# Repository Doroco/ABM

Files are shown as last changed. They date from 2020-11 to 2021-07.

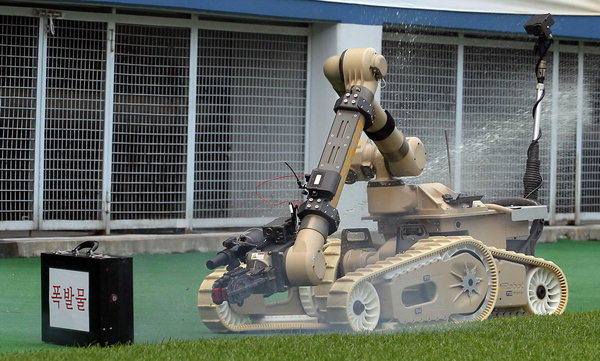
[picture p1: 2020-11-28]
설계파일/final_only/image/부엉이/L20140818.22019191557i1.jpg

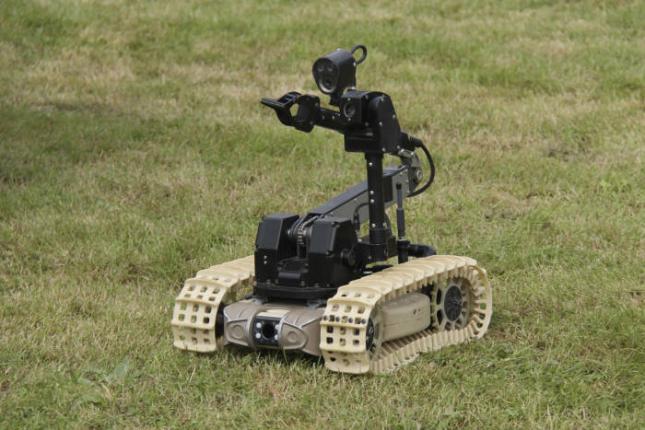
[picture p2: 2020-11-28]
설계파일/final_only/image/부엉이/799672_20160509152558_325_0002.jpg

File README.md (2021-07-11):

# Autonomous driving DDMR agent  

로봇팔이 부착된 Mobile robot이 다양한 Task를 수행합니다.

- 프로젝트 5분 소개영상
https://youtu.be/9r_tR3T8_8s

## 목차

- System Architecture
- Hardware Architecture
- 구현내용
- Project Secenarios
- Reference

### System Architecture
시스템아키텍쳐

### Hardware Architecture
하드웨어 아키텍쳐

### 구현내용

- 모터제어

Global_PathPlanning

- DWA(Dynamic Window Approach)

DWA_SIM

- 실제 주행

ezgif com-gif-maker (2)

- 3-DOF Inverse Kinematics

ezgif com-gif-maker (2)

- Ros와 MCU간의 Serial 통신

### Project Scenarios

- 세부기술 정리(준비중): https://doroco.github.io/ 

### reference
- [1]Fox, D., Burgard, W., & Thrun, S. (1997). The dynamic window approach to collision avoidance. IEEE Robotics & Automation Magazine, 4(1), 23–33. 
- [2]강형석, 「제어기 설계를 위한 DC 모터의 모델 파라미터 측정 및 실험적 보정」, 『한국정밀공학회지』, 제 31권 12호, 한국정밀공학회, pp1147-1154.
김상훈 저,⒊『(DC,AC,BLDC)모터제어』, 서울 : 복두출판사, 2010,pp54-115.
https://pinkwink.kr/732
- [3]Rached Dhaouadi, Dynamic Modelling of Differential-Drive Mobile Robots using Lagrange and Newton-Euler Methodologies: A Unified Framework,Adv Robot Autom,2013,pp3-6.
- [4]Modern Robotics, Kevin M.Lynch, Frank C.Park
.

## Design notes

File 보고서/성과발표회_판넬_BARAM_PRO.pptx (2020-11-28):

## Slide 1

2020학년도 2학기 참빛설계학기(학생주도형) 성과발표회

BARAM_PRO

안전사고감지 및 스마트 초동조치 시스템

창의융합형

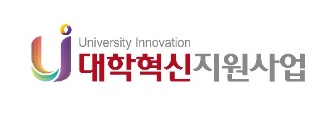
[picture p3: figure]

지도교수 / 최익
(로봇학부)

[개발 배경]

다양한 재난 대응 로봇이 개발되고 있지만, 여러가지 한계점을 보이고 있다.
그 중 재난 초기에 투입 불가능한 문제점을 보완하고자 한다.

[기존 재난 대응 로봇]

재난 발생 초기에는 대피 인원, 구조 요원 등 다양한 동적 물체가 존재
기존 로봇은 물체를 회피하는 것이 불가능 하여 주로 후속조치를 위해 투입

팀원 / 함병일, 최승완
이동규, 이호석 (로봇학부)

[초기 재난 대응 로봇 필요성]

재난 초기에 로봇을 투입하여 초기에 사고를 진압할 수 있도록 한다.

[로봇에 필요한 기술]

Sensing을 통해 사고위치와 자신의 위치, 주변의 환경을 파악한다.
물체 회피를 알고리즘을 통해 충돌로 인한 2차 피해를 방지하며 이동한다.
로봇과 user간의 Data 주고 받기 위한 통신 환경 구축

[System Architecture]

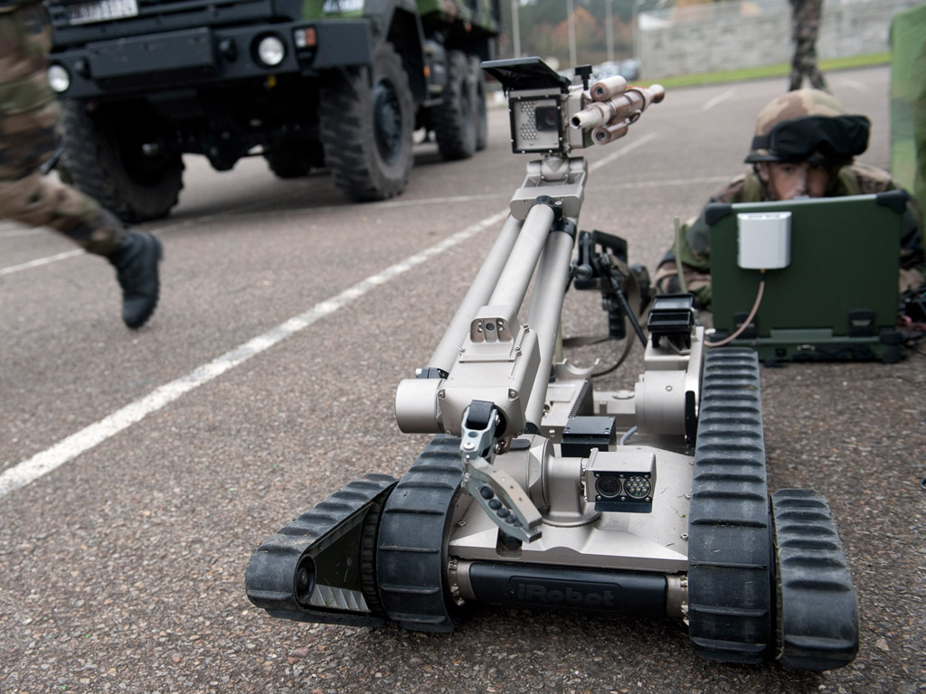
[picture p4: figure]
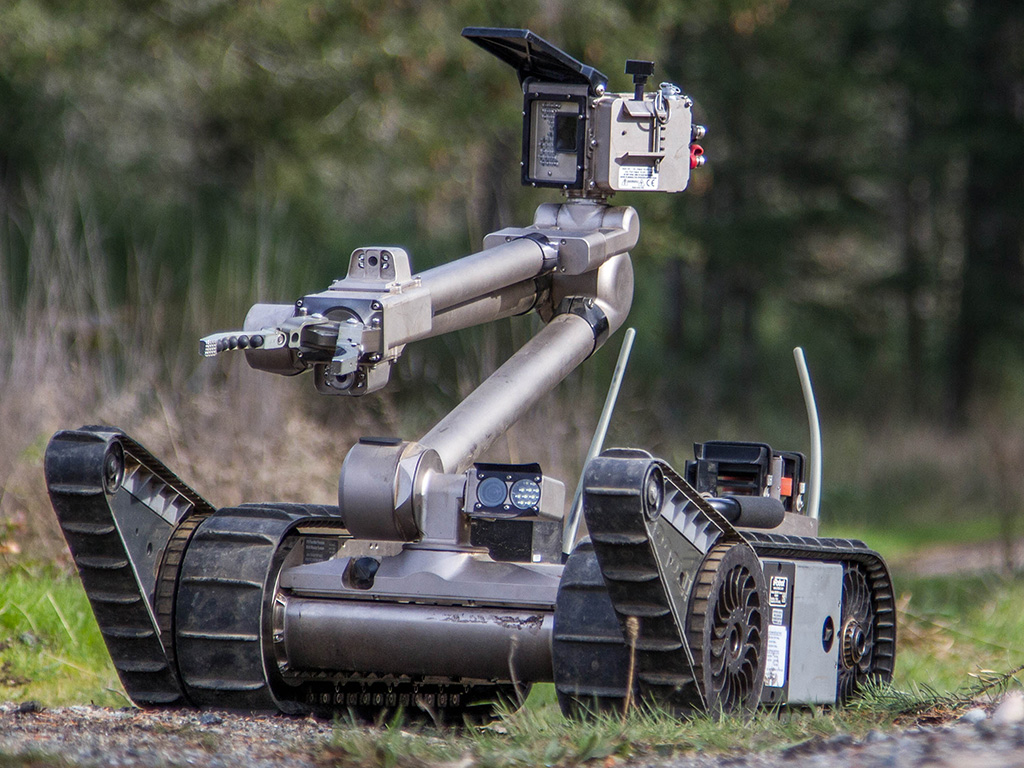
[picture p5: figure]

목표지점 도달 시 초동조치를 위한
로봇 팔 구동

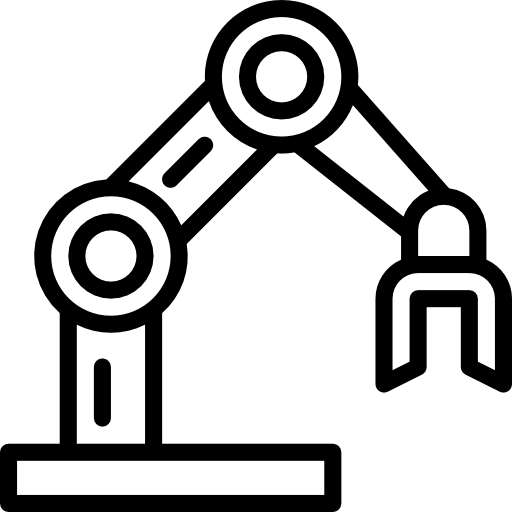
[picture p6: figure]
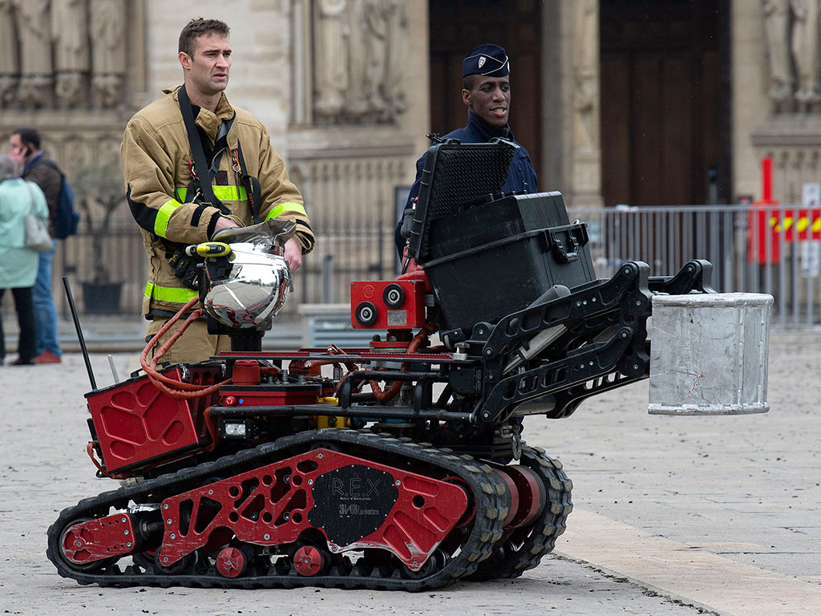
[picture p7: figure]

네비게이션& 회피
LiDAR

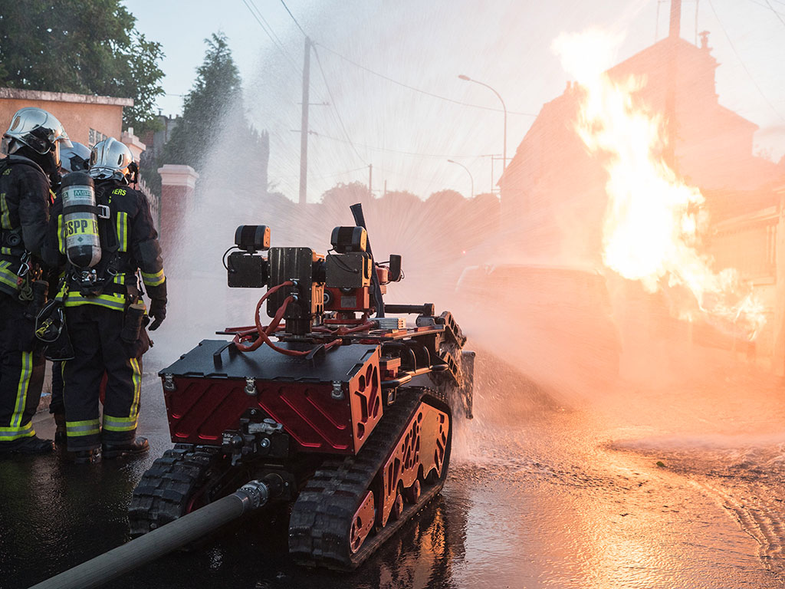
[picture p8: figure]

[개발 목표]

동적 물체를 피하며 최단경로로
목표지점 도달

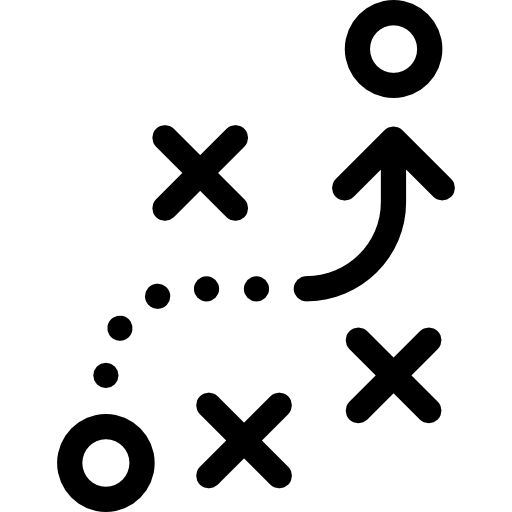
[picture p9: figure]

[하드웨어 구성]

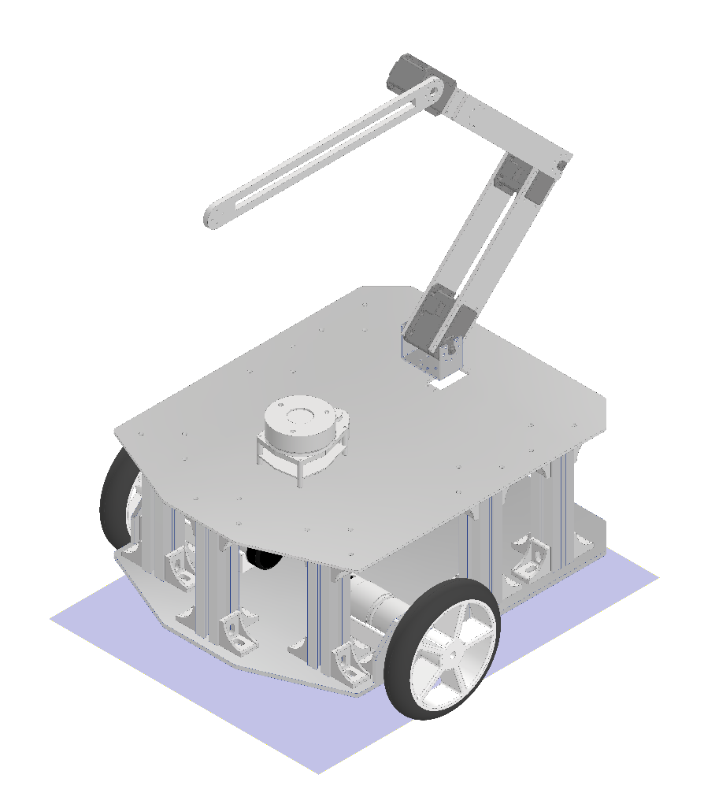
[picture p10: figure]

초동조치
로봇 팔

모바일 로봇

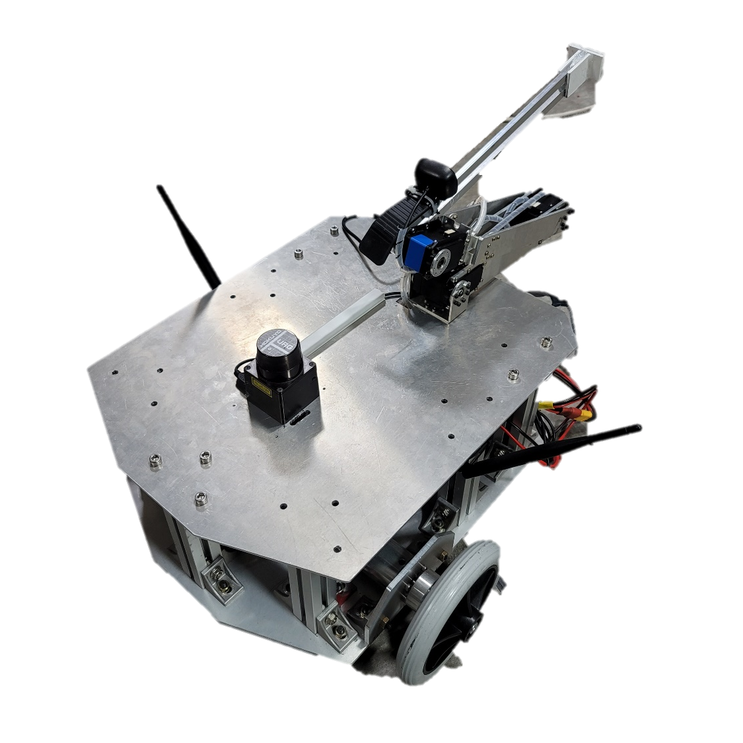
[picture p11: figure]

DDMR

Motor

Encoder

Encoder

Motordriver
(LMD18200)

Motordriver
(LMD18200)

Hardware
DDMR & Manipulator

Current
sensor

Current
sensor

uart

MCU
(STM32F401RE)

Odometry

Robot Pose EKF

v, ω target

Software
Slam & Motion planing

Gmapping

localization

mapping

map image

원격으로 사고 현장 확인
관리자의 판단에 따른 능동적인 조작 기능

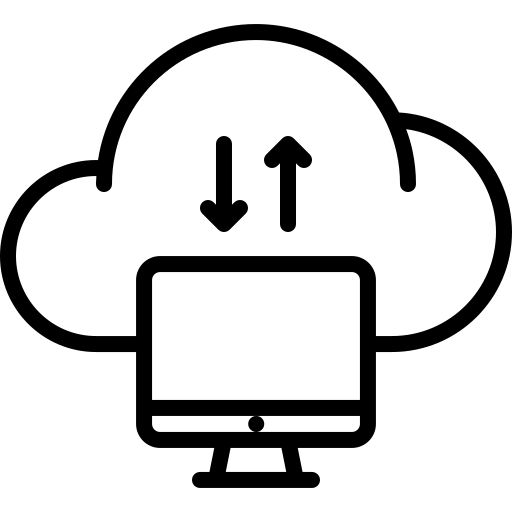
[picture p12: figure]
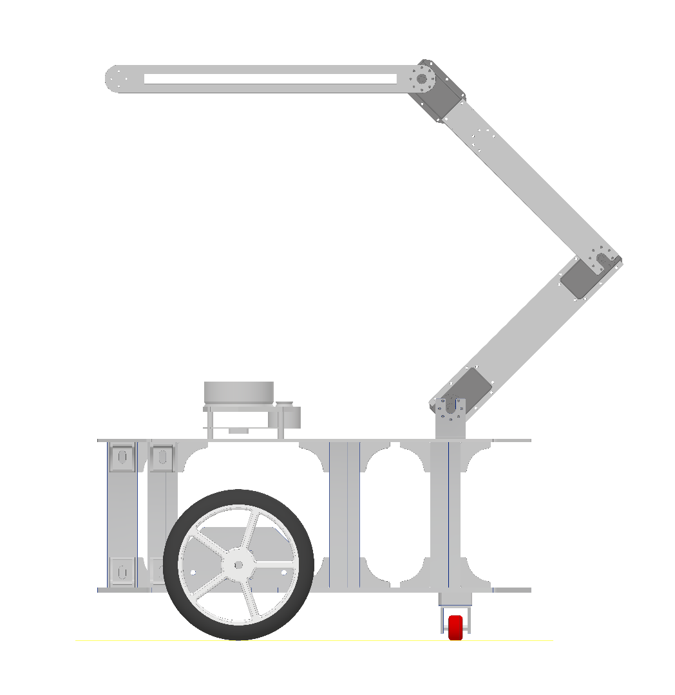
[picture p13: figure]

Manipulator

EX-106

Motor

EX-106

Controller

LiDAR

Camera

scan data

OpenCV

Manipulator state

Navigation

Global Path Planning

waypoint

local Path Planning

object
position

State check

Robot Pose

[구현 시나리오 1]

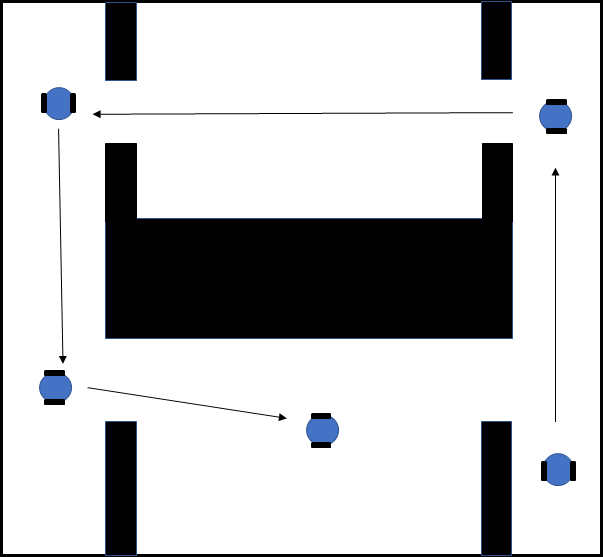
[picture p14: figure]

로봇이 장애물을 피해 자유롭게 움직이며 주변 환경 정보를 저장

[구현 시나리오 2]

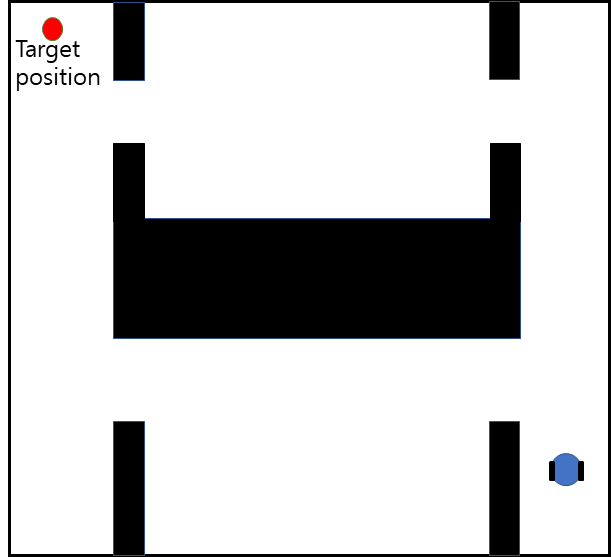
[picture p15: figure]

로봇은 초기위치에서 출발하여, 최단 경로로 목적지에 도착

[구현 시나리오 3]

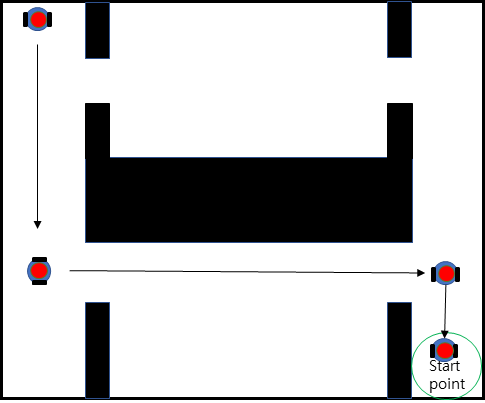
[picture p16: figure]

목적지에서 임무 수행 후 새롭게 정해진 목적지로 이동

EX-106

RS485

HSV

Labeling

Motion planning

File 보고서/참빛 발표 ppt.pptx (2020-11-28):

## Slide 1

안전사고 감지 및 스마트 초동조치 시스템

BARAM_PRO
School of Robotics
지도교수 : 최익
팀원 : 함병일, 최승완, 이동규, 이호석

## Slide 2

Project Introduction

Motive for Selection

1. 다양한 재난 대응 로봇이 연구 개발되고 있지만, 여러가지 한계점을 보이고 있다.
2. 그 중 재난 초기에 투입 불가능한 문제점을 보완하고자 한다.

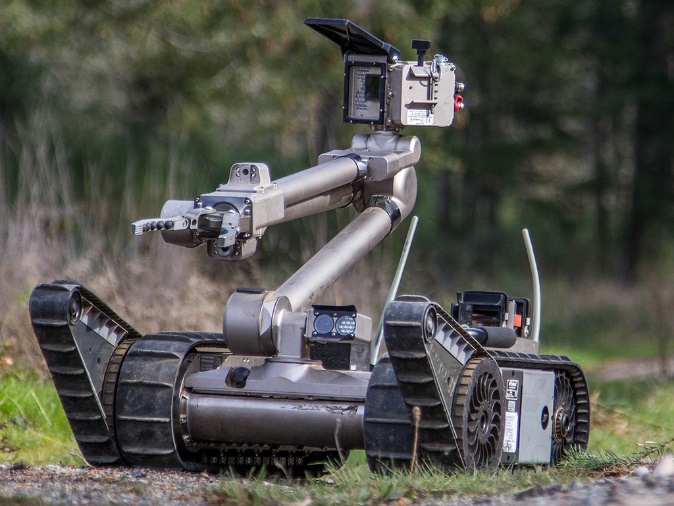
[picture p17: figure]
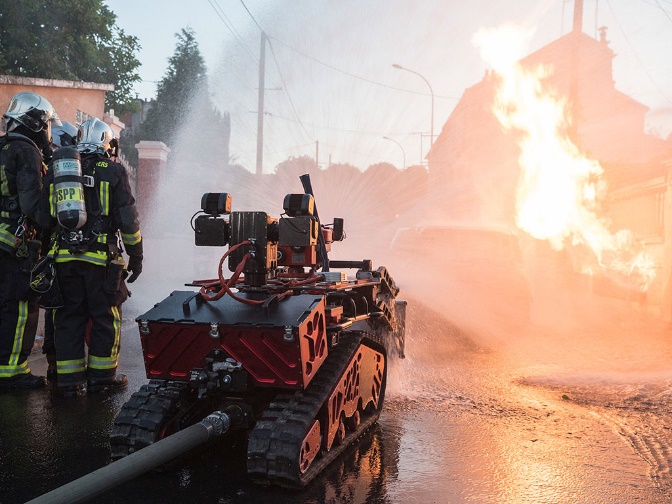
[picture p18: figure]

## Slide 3

Project Introduction

Development Goals

1. 동적 물체를 회피하여 최단 경로로 목표 지점 도달
2. 초동조치를 위한 Manipulator 구동
3. 원격으로 사고 현장 확인
4. 관리자의 판단에 따른 능동적인 조작 기능

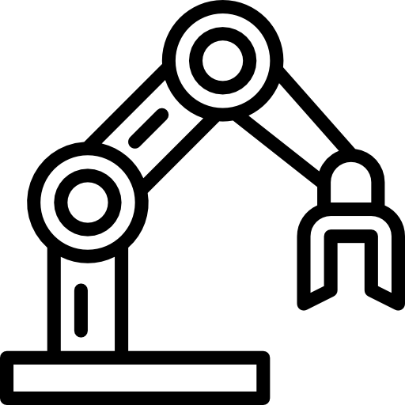
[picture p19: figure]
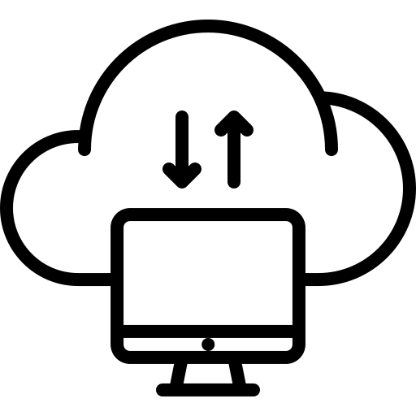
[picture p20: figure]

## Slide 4

Project Contents

Hardware Architecture

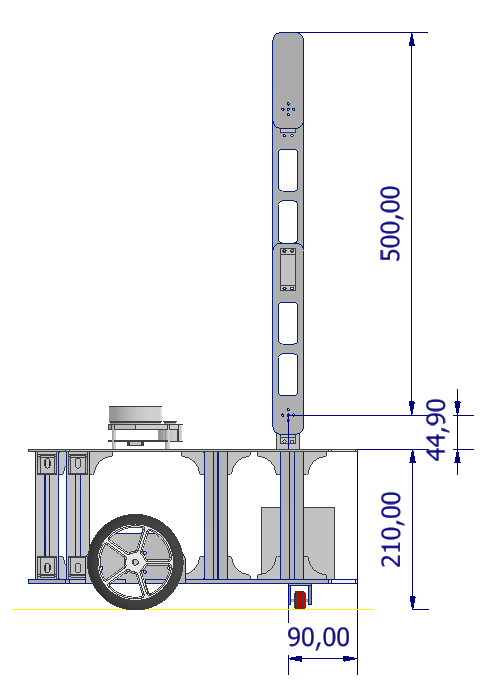
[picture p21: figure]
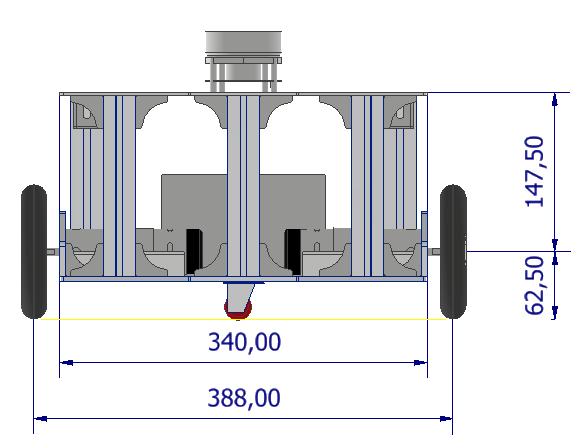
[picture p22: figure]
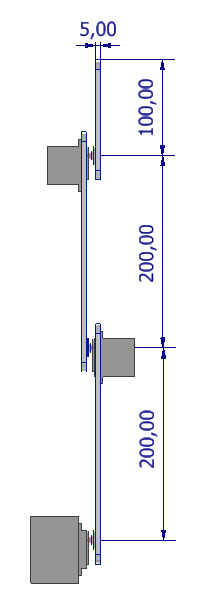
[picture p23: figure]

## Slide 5

Project Contents

System Architecture

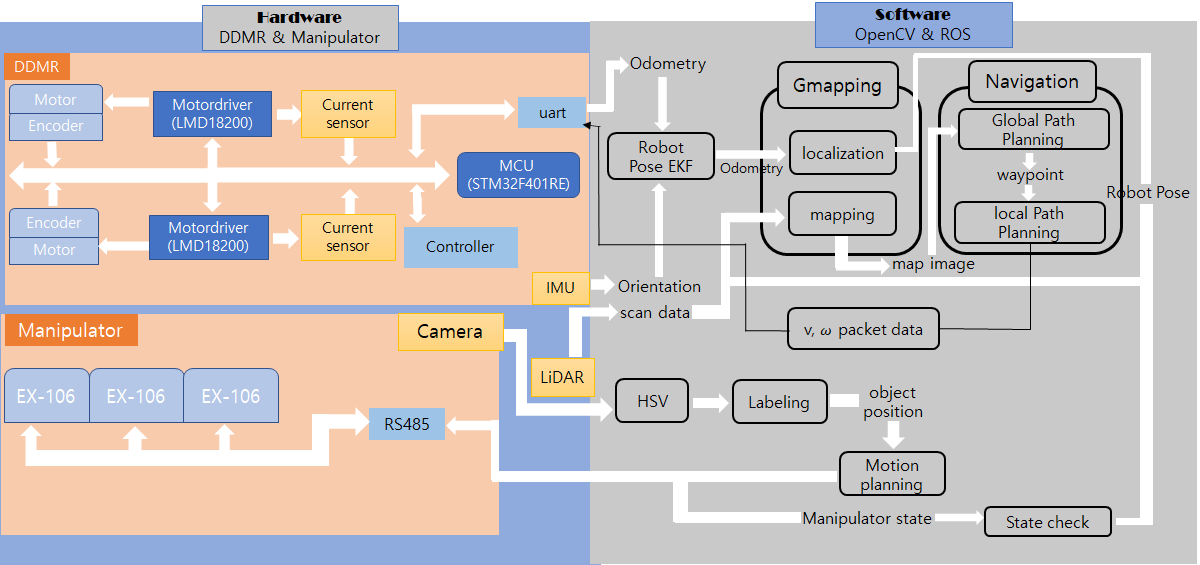
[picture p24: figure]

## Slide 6

Project Contents

Dynamic Window Approach

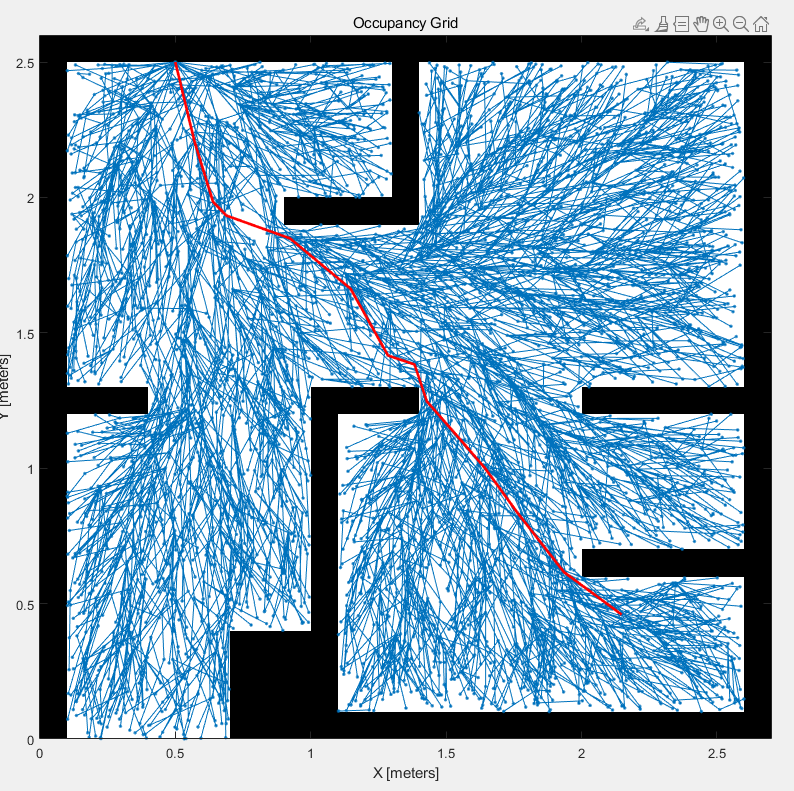
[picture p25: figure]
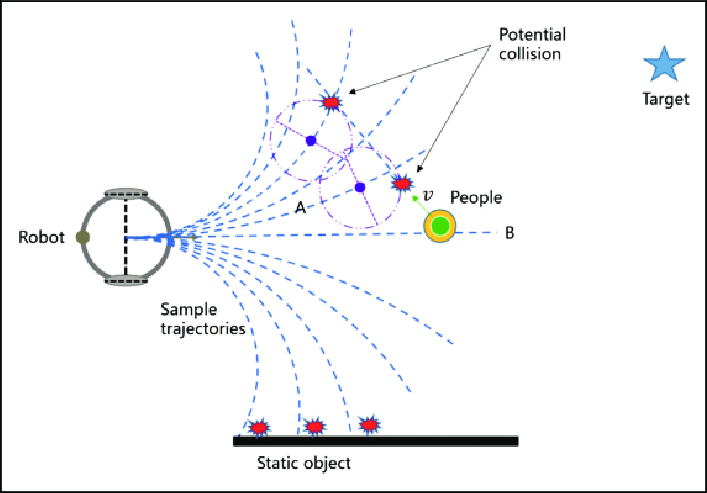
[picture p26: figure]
Illustration of the improved DWA method. DWA: dynamic window approach.

cost(v,ω)=α∙heading(v,ω)+β∙dist(v,ω)+γ∙vel(v,ω)

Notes: 출처:https://www.researchgate.net/figure/Illustration-of-the-improved-DWA-method-DWA-dynamic-window-approach_fig10_317584521
출처:Hugo Berti, A. Sappa, O. AgamennoniPublished 2008EngineeringLatin American Applied Research

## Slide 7

Project Contents

Motor Control


Brushed DC Motor Control System Block Diagram

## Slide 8

Project Contents

Motor Control


Current Control


Position Control

Speed Control

Dynamics

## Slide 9

Project Contents

Manipulator

A planar 3-DOF robot manipulator for simulation. All the links have the... | Download Scientific Diagram

Screw Axes

Newton Raphson Method

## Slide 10

Project Contents

Project Scenarios


로봇이 장애물을 피해 자유롭게 움직이며 주변 환경 정보를 저장


로봇은 초기위치에서 출발하여, 최단 경로로 목적지에 도착

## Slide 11

Project Contents

Project Scenarios


목적지에서 임무 수행 후 새롭게 정해진 목적지 또는 출발지점으로 이동

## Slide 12

Thank You
For Your Attention

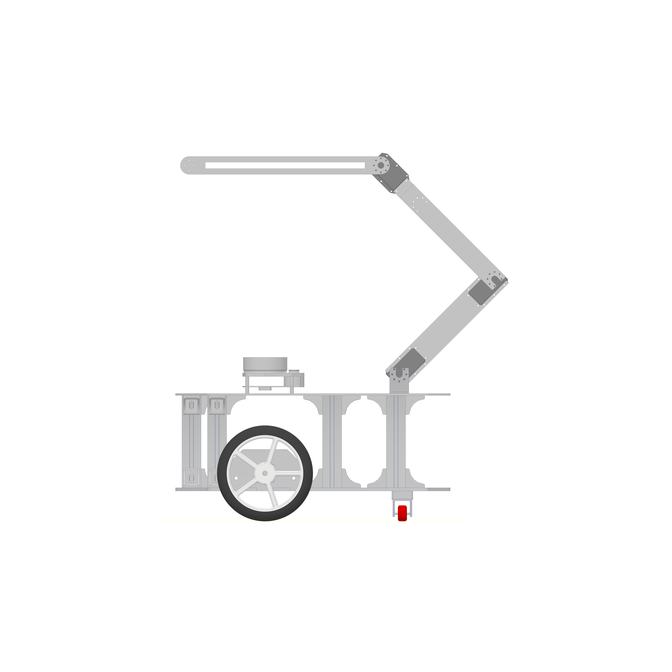
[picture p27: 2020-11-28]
설계파일/final_only/image/부엉이/final_side.tiff

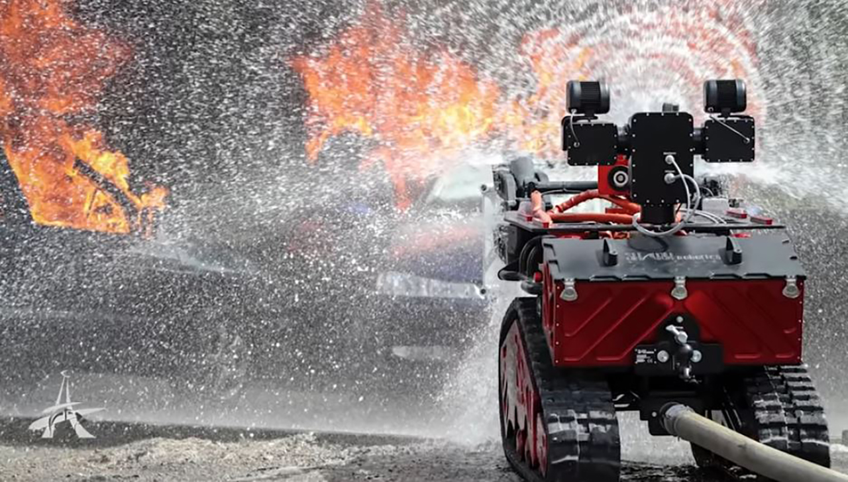
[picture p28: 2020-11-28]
설계파일/final_only/image/부엉이/201904181640067609_img_00.jpg

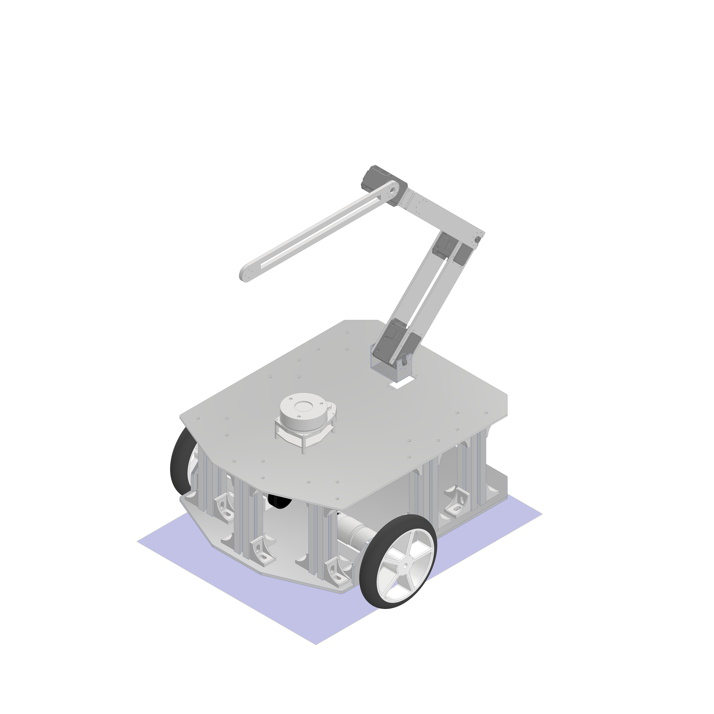
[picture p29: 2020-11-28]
설계파일/final_only/image/부엉이/final.tiff

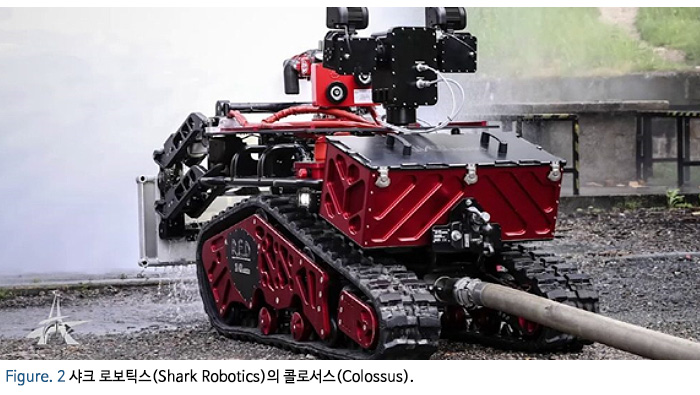
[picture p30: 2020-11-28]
설계파일/final_only/image/부엉이/20200918_pjy_03.jpg

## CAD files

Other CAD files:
설계파일/final_only/145pi_wheel/145pi_tire.iam
설계파일/final_only/145pi_wheel/OldVersions/145pi_tire.0006.iam
설계파일/final_only/145pi_wheel/OldVersions/tire.0007.ipt
설계파일/final_only/145pi_wheel/OldVersions/wheel.0002.ipt
설계파일/final_only/145pi_wheel/tire.ipt
설계파일/final_only/145pi_wheel/wheel.ipt
설계파일/final_only/LIDAR/OldVersions/RPLIDAR_A1.0005.iam
설계파일/final_only/LIDAR/OldVersions/base.0001.ipt
설계파일/final_only/LIDAR/OldVersions/base.0002.ipt
설계파일/final_only/LIDAR/OldVersions/sensor.0001.ipt
설계파일/final_only/LIDAR/RPLIDAR_A1.iam
설계파일/final_only/LIDAR/base.ipt
설계파일/final_only/LIDAR/sensor.ipt
설계파일/final_only/LIDAR/wheel.ipt
설계파일/final_only/bottom.ipt
설계파일/final_only/braket2.ipt
설계파일/final_only/castor/OldVersions/castor_1inch.0010.iam
설계파일/final_only/castor/OldVersions/castor_link.0002.ipt
설계파일/final_only/castor/OldVersions/castor_link2.0005.ipt
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

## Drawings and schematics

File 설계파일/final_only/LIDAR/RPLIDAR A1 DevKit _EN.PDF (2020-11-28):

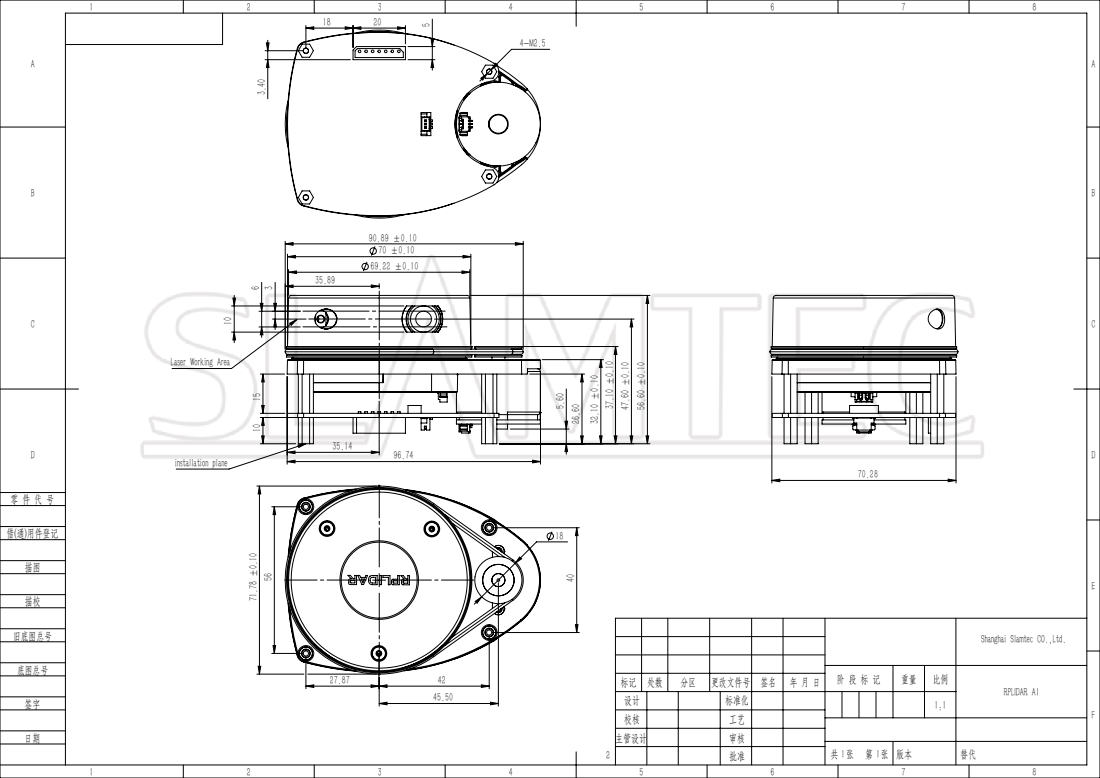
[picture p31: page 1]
installation plane

Laser Working Area

Shanghai Slamtec CO.,Ltd.

阶 段 标 记 | 重量 | 比例 | RPLIDAR A1

标记 | 处数 | 分区 | 更改文件号 | 签名 | 年 月 日
设计 | | | 标准化 | | | | | 1:1
校核 | | | 工艺
主管设计 | | | 审核

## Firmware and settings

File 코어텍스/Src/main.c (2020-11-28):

/**
  ******************************************************************************
  * @file           : main.c
  * @brief          : Main program body
  ******************************************************************************
  ** This notice applies to any and all portions of this file
  * that are not between comment pairs USER CODE BEGIN and
  * USER CODE END. Other portions of this file, whether 
  * inserted by the user or by software development tools
  * are owned by their respective copyright owners.
  *
  * COPYRIGHT(c) 2020 STMicroelectronics
  *
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
  ******************************************************************************
  */
/* Includes ------------------------------------------------------------------*/
#include "main.h"
#include "stm32f4xx_hal.h"

/* USER CODE BEGIN Includes */
#include "string.h"
#include "math.h"

/* USER CODE END Includes */

ADC_HandleTypeDef hadc1;
DMA_HandleTypeDef hdma_adc1;

TIM_HandleTypeDef htim2;
TIM_HandleTypeDef htim3;
TIM_HandleTypeDef htim4;

UART_HandleTypeDef huart6;
DMA_HandleTypeDef hdma_usart6_rx;

/* USER CODE BEGIN PV */
#define dt 0.0002
#define dt2 0.0001
#define dt10 0.02
#define pi 3.141592653589793
#define ppr 3724
#define RX_BUFFER_SIZE 18
#define TX_BUFFER_SIZE 12
#define R 0.075
#define L 0.2125
#define get_dma_data_length() huart6.hdmarx->Instance->NDTR
#define get_dma_total_size() huart6.RxXferSize
//#define tau 0.00048

volatile int32_t encoder_cnt_R = 0;
volatile int32_t encoder_cnt_L = 0;
volatile int32_t encoder_cnt_pre_R = 0;
volatile int32_t encoder_cnt_pre_L = 0;

volatile int16_t cnt_R = 0;
volatile int16_t cnt_L = 0;

volatile double angular_velocity_R = 0;
volatile double angular_velocity_L = 0;
volatile double angular_velocity_pre_R = 0;
volatile double angular_velocity_pre_L = 0;
volatile double theta_R = 0;
volatile double theta_L = 0;
volatile double delta_s = 0;
volatile double delta_theta = 0;

//volatile int g_cnt = 0;

volatile uint16_t Motor_CCR_R = 0;
volatile uint16_t Motor_CCR_L = 0;
volatile uint16_t timer = 0;
volatile uint16_t ctimer = 0;
volatile uint16_t ptimer = 0;
volatile uint16_t ktimer = 0;


volatile double rep_r = 0;
volatile double rep_l = 0;
volatile double rep_pre_r = 0;
volatile double rep_pre_l = 0;
volatile double Kps[2] = {80.5, 61.5};//{74, 71};68 58
volatile double Kis[2] = {71.24, 68.12};//{55, 57};45 62
volatile double Kas[2] = {0.00455, 0.00555};
volatile double Es[2] = {0, 0};
volatile double Eis[2] = {0, 0};
volatile double speed[2] = {0, 0};

volatile int16_t lin_vel;
volatile int16_t ang_vel;

volatile uint8_t lin_vel_L;
volatile uint8_t lin_vel_H;
volatile uint8_t ang_vel_L;
volatile uint8_t ang_vel_H;

volatile int16_t sop = 0x55;
volatile int16_t checksum;

volatile uint8_t checksum_H;
volatile uint8_t checksum_L;

volatile char packet[RX_BUFFER_SIZE];
//volatile uint8_t parsing[RX_BUFFER_SIZE];

volatile int16_t plin_vel;
volatile int16_t pang_vel;
volatile int16_t pcheck;




uint8_t rx_dma_buffer[RX_BUFFER_SIZE];
uint8_t rx_buffer[RX_BUFFER_SIZE];
uint32_t rx_size = 0;
uint8_t tx_len;
uint8_t tx_buffer[TX_BUFFER_SIZE];

uint16_t _prevRxXferedCount = 0;
uint16_t _lastRxXferedCount = 0;


uint16_t old_pos = 0;
uint16_t pos;
uint16_t umm;
uint16_t umm2;
uint16_t umm3;

int16_t trans_x;
int16_t trans_y;
int16_t trans_yaw;

uint8_t trans_x_L;
uint8_t trans_x_H;
uint8_t trans_y_L;
uint8_t trans_y_H;
uint8_t trans_yaw_L;
uint8_t trans_yaw_H;
int16_t trans_checksum;

uint8_t trans_checksum_L;
uint8_t trans_checksum_H;
uint8_t tx_odom[12];
uint8_t dir = 0;
volatile double odometry[3];


/* USER CODE END PV */

void SystemClock_Config(void);
static void MX_GPIO_Init(void);
static void MX_DMA_Init(void);
static void MX_TIM4_Init(void);
static void MX_TIM3_Init(void);
static void MX_TIM2_Init(void);
static void MX_USART6_UART_Init(void);
static void MX_ADC1_Init(void);

void HAL_TIM_MspPostInit(TIM_HandleTypeDef *htim);
                                

/* USER CODE BEGIN PFP */

/* USER CODE END PFP */

/* USER CODE BEGIN 0 */

void Uart_rx_dma_handler() {
        

  uint8_t cnt;
  uint8_t i;
  uint8_t temp[12];
  
  rx_size = 0;
  pos = get_dma_total_size() - get_dma_data_length();
  
  i = 0;
  
  while(1) {
    if((rx_dma_buffer[i] == rx_dma_buffer[i+1]) && (rx_dma_buffer[i] == 'U')) break;
    else i++;
  }
  
  if(pos != old_pos) {
    if(pos > old_pos) {
        //umm++;//test
        memcpy(&rx_buffer[old_pos], &rx_dma_buffer[(old_pos+i)%RX_BUFFER_SIZE], sizeof(uint8_t)*(pos - old_pos));
        rx_size += pos - old_pos;
    }else {
        //umm2++;//test
        memcpy(&rx_buffer[old_pos], &rx_dma_buffer[(old_pos+i)%RX_BUFFER_SIZE], sizeof(uint8_t)*(get_dma_total_size() - old_pos));
        rx_size += get_dma_total_size() - old_pos;
        if(pos > 0){
                memcpy(&rx_buffer[get_dma_total_size() - old_pos], &rx_dma_buffer[0], sizeof(uint8_t)*pos);
                rx_size += get_dma_total_size() - old_pos;
        }
    }
    old_pos = pos;
    if(rx_size > 0) {
      for(cnt = 0;cnt<rx_size;cnt++) {
        pcheck = (rx_buffer[6] << 8) | rx_buffer[7] & 0xff;
        if(pcheck == rx_buffer[0] + rx_buffer[1] + rx_buffer[2] + rx_buffer[3] + rx_buffer[4] + rx_buffer[5]) {
          plin_vel = (rx_buffer[2] << 8) | rx_buffer[3] & 0xff;
          pang_vel = (rx_buffer[4] << 8) | rx_buffer[5] & 0xff;
          
        }
      }
    }
  }
}

void HAL_TIM_PeriodElapsedCallback(TIM_HandleTypeDef *htim) {
  if(htim == &htim4) {
    //HAL_GPIO_WritePin(GPIOC,GPIO_PIN_8,GPIO_PIN_SET);
    timer++;
    
    if(timer ==2) {
      ctimer++;//////////
      ptimer++;
      
      timer = 0;
      
      rep_pre_r = cos(pi);
      
      //if(ptimer < 91000) ptimer++;
      
      //TIM4 CHN2 R CHN1 L
      //DIR PA5 L PA4 R
      //ADC IN14 L IN15 R
     
     if(ctimer == 100){
        
        encoder_cnt_pre_R = encoder_cnt_R;
        encoder_cnt_pre_L = encoder_cnt_L;
        encoder_cnt_R = TIM3->CNT;
        encoder_cnt_L = TIM2->CNT;
        
        if((pang_vel < 1000 & pang_vel > -1000) & (plin_vel < 1000 & plin_vel > -1000)) {
          rep_r = 0.001*(pang_vel*L + plin_vel)/R;
          rep_l = 0.001*(-pang_vel*L + plin_vel)/R;
        }
        
        cnt_R = encoder_cnt_R-encoder_cnt_pre_R;
        cnt_L = encoder_cnt_L-encoder_cnt_pre_L;
        
        if(encoder_cnt_R < 100 & encoder_cnt_pre_R > 65450 ) cnt_R += 65535;
        else if(encoder_cnt_pre_R < 100 & encoder_cnt_R > 65000) cnt_R -= 65535;
        if(encoder_cnt_L < 100 & encoder_cnt_pre_L > 65450 ) cnt_L += 65535;
        else if(encoder_cnt_pre_L < 100 & encoder_cnt_L > 65000) cnt_L -= 65535;
        
        
        theta_R = (double)(2*pi*cnt_R/ppr);
        theta_L = (double)(2*pi*cnt_L/ppr);
        angular_velocity_R = (double)theta_R/dt10;
        angular_velocity_L = (double)theta_L/dt10;
        

        
        
        Es[0] = (double)(rep_r - angular_velocity_R);
        Eis[0] += (double)Es[0];
        speed[0] = (double)Kps[0] * Es[0] + Kis[0] * Eis[0];
        
        if(speed[0] >= 4198) {
          Eis[0] -= (double)1/Kps[0]*(speed[0] - 4198);
          speed[0] = 4198;
        }
        else if(speed[0] <= -4198) {
          Eis[0] -= (double)1/Kps[0]*(speed[0] - (-4198));
          speed[0] = -4198;
        }
        
        Es[1] = (double)(rep_l - angular_velocity_L);
        Eis[1] += (double)Es[1];
        speed[1] = (double)Kps[1] * Es[1] + Kis[1] * Eis[1];
        if(speed[1] >= 4198) {
          Eis[1] -= (double)1/Kps[1]*(speed[1] - 4198);
          speed[1] = 4198;
        }
        else if(speed[1] <= -4198) {
          Eis[1] -= (double)1/Kps[1]*(speed[1] - (-4198));
          speed[1] = -4198;
        }
        
        if(speed[1] < 260 && speed[1] > -260)     speed[1] = 0;


        
        if(speed[1]<0) {  //哭率官柠 开规氢
          HAL_GPIO_WritePin(GPIOA,GPIO_PIN_5,GPIO_PIN_SET);
          speed[1]=-speed[1];
          dir = 0;
        }
        else {
          HAL_GPIO_WritePin(GPIOA,GPIO_PIN_5,GPIO_PIN_RESET);  
          //speed[1]=speed[1];
          dir = 1;
        }
        if(speed[0] < 0 ) {
          HAL_GPIO_WritePin(GPIOA,GPIO_PIN_4,GPIO_PIN_RESET);
          speed[0] = -speed[0];
        }
        else {
          HAL_GPIO_WritePin(GPIOA,GPIO_PIN_4,GPIO_PIN_SET);
          //speed[0] = speed[0];
        }
        
        Motor_CCR_R = (uint16_t)speed[0];
        Motor_CCR_L = (uint16_t)speed[1];
        
        //TIM4->CCR1 = Motor_CCR_L;
        //TIM4->CCR2 = Motor_CCR_R;
        
        delta_s = (double)R*(theta_R + theta_L)/2.0;
        delta_theta = (double)R*(theta_R - theta_L)/(2.0*L);
        odometry[0] += delta_s * cos(odometry[2] + (delta_theta/2.0));
        odometry[1] += delta_s * sin(odometry[2] + (delta_theta/2.0));
        odometry[2] += delta_theta;
        if(odometry[2] < -1 * pi) { 
          odometry[2] += 2.0*pi;
        }
        else if(odometry[2] > pi) {
          odometry[2] -= 2.0*pi;
        }
        
        
        
        ctimer = 0;
        //rep_pre_r = rep_r;
        //rep_pre_l = rep_l;
        
      }
     if(ptimer == 1500) {
      
       trans_x = (int16_t)1000*odometry[0];
       trans_y = (int16_t)1000*odometry[1];
       trans_yaw = (int16_t)1000*odometry[2];

        trans_x_L = trans_x & 0xff;
        trans_x_H = trans_x >>8;
        trans_y_L = trans_y & 0xff;;
        trans_y_H = trans_y >>8;
        trans_yaw_L = trans_yaw & 0xff;;
        trans_yaw_H = trans_yaw >>8;
        trans_checksum = sop+sop+trans_x_L+trans_x_H+trans_y_L+trans_y_H+trans_yaw_L+trans_yaw_H;
        trans_checksum_L = trans_checksum & 0xff;
        trans_checksum_H = trans_checksum >>8;
        sprintf(tx_odom,"%c%c%c%c%c%c%c%c%c%c\n",sop,sop,trans_x_H,trans_x_L,
                  trans_y_H,trans_y_L,trans_yaw_H,trans_yaw_L,trans_checksum_H,trans_checksum_L);
        HAL_UART_Transmit(&huart6,tx_odom,sizeof(tx_odom), 10);
         
        ptimer = 0;
     }/////////
      
      
      
    }
    TIM4->CCR1 = Motor_CCR_L;
    TIM4->CCR2 = Motor_CCR_R;


    //HAL_GPIO_WritePin(GPIOC,GPIO_PIN_8,GPIO_PIN_RESET);
   }
}


/*
void HAL_UART_CallBack(UART_HandleTypeDef *huart) {
  
  HAL_GPIO_TogglePin(GPIOA, GPIO_PIN_5);
  tx_len = sizeof(tx_buffer) -1;
  HAL_UART_Transmit(&huart6, tx_buffer, tx_len, HAL_MAX_DELAY);

}*/

/* USER CODE END 0 */

/**
  * @brief  The application entry point.
  *
  * @retval None
  */
int main(void)
{
  /* MCU Configuration----------------------------------------------------------*/

  /* Reset of all peripherals, Initializes the Flash interface and the Systick. */
  HAL_Init();

  /* Configure the system clock */
  SystemClock_Config();

  /* Initialize all configured peripherals */
  MX_GPIO_Init();
  MX_DMA_Init();
  MX_TIM4_Init();
  MX_TIM3_Init();
  MX_TIM2_Init();
  MX_USART6_UART_Init();
  MX_ADC1_Init();
  /* USER CODE BEGIN 2 */

  HAL_TIM_Base_Start_IT(&htim4);
  HAL_UART_Receive_DMA(&huart6, rx_dma_buffer, RX_BUFFER_SIZE);
  //HAL_UART_Receive_IT(&huart6,rx_dma_buffer,RX_BUFFER_SIZE);
  HAL_TIM_PWM_Start(&htim4, TIM_CHANNEL_1);
  HAL_TIMEx_PWMN_Start(&htim4, TIM_CHANNEL_1);
  HAL_TIM_PWM_Start(&htim4, TIM_CHANNEL_2);
  HAL_TIMEx_PWMN_Start(&htim4, TIM_CHANNEL_2);
  HAL_TIM_Encoder_Start(&htim2,TIM_CHANNEL_ALL);
  HAL_TIM_Encoder_Start(&htim3,TIM_CHANNEL_ALL);
  HAL_GPIO_WritePin(GPIOA,GPIO_PIN_4,GPIO_PIN_SET);//R RESET 沥 SET 开
  HAL_GPIO_WritePin(GPIOA,GPIO_PIN_5,GPIO_PIN_SET);
  
  
  /* USER CODE END 2 */

  /* Infinite loop */
  /* USER CODE BEGIN WHILE */
  while (1)
  {
    /*g_cnt = 0;
    
    
    pcheck = (rx_buffer[6] << 8) | rx_buffer[7] & 0xff;
    if(pcheck == rx_buffer[0] + rx_buffer[1] + rx_buffer[2] + rx_buffer[3] + rx_buffer[4] + rx_buffer[5]) {
      plin_vel = (rx_buffer[2] << 8) | rx_buffer[3] & 0xff;
      pang_vel = (rx_buffer[4] << 8) | rx_buffer[5] & 0xff;
    }
    */
    Uart_rx_dma_handler();

  /* USER CODE END WHILE */

  /* USER CODE BEGIN 3 */

  }
  /* USER CODE END 3 */

}

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


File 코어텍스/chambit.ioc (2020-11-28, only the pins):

Mcu.UserName=STM32F401RETx
PA0-WKUP.Signal=S_TIM2_CH1_ETR
PA1.Signal=S_TIM2_CH2
PA4.Signal=GPIO_Output
PA5.Signal=GPIO_Output
PA6.Signal=S_TIM3_CH1
PA7.Signal=S_TIM3_CH2
PB0.Signal=ADCx_IN8
PB6.Signal=S_TIM4_CH1
PB7.Signal=S_TIM4_CH2
PC14-OSC32_IN.Signal=RCC_OSC32_IN
PC15-OSC32_OUT.Signal=RCC_OSC32_OUT
PC5.Signal=ADCx_IN15
PC6.Signal=USART6_TX
PC7.Signal=USART6_RX
PC8.GPIO_Label=sampling
PC8.Signal=GPIO_Output

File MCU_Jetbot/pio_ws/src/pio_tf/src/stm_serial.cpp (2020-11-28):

#include "ros/ros.h"
#include "std_msgs/String.h"
#include "std_msgs/Empty.h"
#include "geometry_msgs/Twist.h"
#include "geometry_msgs/Pose2D.h"
#include "serial/serial.h"
#include "cstdlib"
#include "math.h"
#include "stdio.h"
#include "t_serial.h"

serial::Serial ser;

t_serial g_serial;

int16_t x;
int16_t z;
int16_t checksum;

uint8_t tx_x_L;
uint8_t tx_x_H;
uint8_t tx_z_L;
uint8_t tx_z_H;
uint8_t tx_checksum_L;
uint8_t tx_checksum_H;

char tx_twist[10];
uint8_t tx_twist2[10];

void write_callback(const std_msgs::String::ConstPtr& msg)
{
    ROS_INFO_STREAM("Writing to serial port" << msg->data);

    ser.write(msg->data);
}

void cmd_vel_callback(const geometry_msgs::Twist::ConstPtr& msg )
{

  char s2[17];
  int16_t zero = 85;
  uint8_t zero_H = zero >> 8;
  uint8_t zero_L = zero &0xff;
  char zerostr[10]={1,1,1};
  printf("zero : %d",zero);
  printf("zero_H : %d",zero_H);
  printf("zero_L : %d",zero_L);

  sprintf(zerostr,"%c%x",zero_L,zero_H);
  printf("zero is %s\n",zerostr);
  uint8_t sop = 0x55;
  x = msg->linear.x*1000;
  z = msg->angular.z*1000;
  //  z = z*1000;
  //  x = x*1000;
    std::cout << "linear x " << (int)x;
    std::cout << "angular z " << (int)z;
   // z = (int16_t)z*100;
   // x = (int16_t)x*500;

   // ROS_INFO_STREAM("linear x*100= " << 10934);
   // ROS_INFO_STREAM("angular z*100= " << z);

    tx_x_H = x >>8;
    tx_x_L = x & 0xff;
    tx_z_H = z >>8;
    tx_z_L = z & 0xff;

    checksum = sop+sop+tx_x_H+tx_x_L+tx_z_H+tx_z_L;

    tx_checksum_H = checksum >> 8;
    tx_checksum_L = checksum & 0xff;

    std::cout << "qWtx_x_H " << tx_x_H << std::endl;
    std::cout << "tx_x_L "<< tx_x_L << std::endl;
    std::cout << "tx_z_H "<< tx_z_H << std::endl;
    std::cout << "tx_z_L "<< tx_z_L << std::endl;
    std::cout << "tx_check_H "<< tx_checksum_H << std::endl;
    std::cout << "tx_ehck_L " << tx_checksum_L << std::endl;
//    std::cout << "tx_twist = " << tx_twist << std::endl;

   // sprintf(tx_twist, "%c%c%c%c%c%c%c%c\n",sop,sop,tx_x_H,tx_x_L,tx_z_H,tx_z_L,tx_checksum_H,tx_checksum_L);
    tx_twist[0] = sop;
    tx_twist[1] = sop;
    tx_twist[2] = tx_x_H;
    tx_twist[3] = tx_x_L;
    tx_twist[4] = tx_z_H;
    tx_twist[5] = tx_z_L;
    tx_twist[6] = tx_checksum_H;
    tx_twist[7] = tx_checksum_L;
    tx_twist[8] = '\n';
    tx_twist[9] = '\0';

    //  sprintf(s2, "%lf", );
    std::cout << "tx_twist =  " << tx_twist <<std::endl;
    for(int j  = 0; j<10;j++) {
        tx_twist2[j]=tx_twist[j];
    }
    ser.write(tx_twist2,sizeof(int8_t)*10);
    ser.write(tx_twist2,sizeof(int8_t)*10);
    ser.write(tx_twist2,sizeof(int8_t)*10);
    ser.write(tx_twist2,sizeof(int8_t)*10);

    //    ser.write(tx_twist);
  //  ser.write(tx_twist[0]);

}

int main (int argc, char** argv)
{
    ros::init(argc, argv, "stm_serial");
    ros::NodeHandle nh;

    ros::Subscriber write_sub = nh.subscribe("write", 100, write_callback);
    ros::Publisher read_pub = nh.advertise<std_msgs::String>("read", 100);
    ros::Publisher odom_pub = nh.advertise<geometry_msgs::Pose2D>("odom",100);
    ros::Subscriber goal_vel = nh.subscribe("cmd_vel",100,cmd_vel_callback);

    int parsing_i;
    geometry_msgs::Pose2D odom_data;
    uint8_t parsing[12];
    int16_t rx_odom_x;
    int16_t rx_odom_y;
    int16_t rx_odom_yaw;
    int16_t rx_checksum;

    std::string port;
    //int baudrate;
    nh.param("stm_serial/Port",port,std::string("/dev/ttyUSB0"));
    cout << port <<std::endl;
//    if(!g_serial.Open(const_cast<char*>(port.c_str()), baudrate)){
//        cout << "device is not opened! " << endl;
//    }

/*
    uint8_t rx_x_L;
    uint8_t rx_x_H;
    uint8_t rx_y_L;
    uint8_t rx_y_H;
    uint8_t rx_yaw_L;
    uint8_t rx_yaw_H;
    uint8_t rx_checksum_L;
    uint8_t rx_checksum_H;*/

    try
    {
        ser.setPort(port);
        ser.setBaudrate(115200);
        serial::Timeout to = serial::Timeout::simpleTimeout(100);
        ser.setTimeout(to);
        ser.open();


    }
    catch (serial::IOException& e)
    {
        ROS_ERROR_STREAM("Unable to open port ");
        return -1;
    }

    if(ser.isOpen())
    {
        ROS_INFO_STREAM("Serial Port initialized");
    }
    else
    {
        return -1;
    }

    ros::Rate loop_rate(10);

    while(ros::ok())
    {

        ros::spinOnce();

        if(ser.available())
        {
            ROS_INFO_STREAM("Reading from serial port");
            std_msgs::String result;
            result.data = ser.read(ser.available());

            while (!(parsing_i ==11)) {
                parsing[parsing_i]=result.data[parsing_i];
                parsing_i++;
            }
            parsing_i=0;
            rx_checksum = (parsing[8] << 8) | parsing[9] & 0xff;
            std::cout << "checksum = %c\n" << rx_checksum << std::endl;
            //printf("checksum is a  %x\n",rx_checksum);
            std::cout << (parsing[0] + parsing[1] + parsing[2] + parsing[3] + parsing[4] + parsing[5]);
            if (rx_checksum ==(int16_t) parsing[0] + parsing[1] + parsing[2] + parsing[3] + parsing[4] + parsing[5]+parsing[6]+parsing[7]) {
                     std::cout << "그것은 오른쪽\n"<< std::endl;
                     rx_odom_x = (parsing[2] << 8) | parsing[3] & 0xff;
                     rx_odom_y = (parsing[4] << 8) | parsing[5] & 0xff;
                     rx_odom_yaw = (parsing[6] << 8) | parsing[7] & 0xff;
                     std::cout << "rx_odom_x is : %d\n"<< rx_odom_x << std::endl;
                     std::cout << "rx_odom_y is : %d\n" << rx_odom_y << std::endl;
                     std::cout << "rx_odom_yaw is : %d\n" <<rx_odom_yaw<< std::endl;
                     odom_data.x = (double) rx_odom_x/1000;
                     odom_data.y = (double) rx_odom_y/1000;
                     odom_data.theta = (double) rx_odom_yaw/1000;
                     odom_pub.publish(odom_data);
            }
            else {
                ROS_INFO("error : ");
              //  ROS_INFO("rx_odom_x is : %d\n",rx_odom_x);
             //   printf("rx_odom_y is : %d\n", rx_odom_y);
             //   printf("rx_odom_yaw is : %d\n", rx_odom_yaw);
            }
            //ROS_INFO_STREAM("Read: " << result.data);
            read_pub.publish(result);

        }
        loop_rate.sleep();
    }
}

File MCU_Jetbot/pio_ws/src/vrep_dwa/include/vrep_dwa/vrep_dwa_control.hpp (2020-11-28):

/**
* @brief Franka robot controller in V-REP
* @detail Get joint angle
* @author JiminLee
* @date 2018-07-27
* @version 0.0.1
*/
#ifndef SIMULATION_INTERFACE_H
#define SIMULATION_INTERFACE_H

#include <ros/ros.h>
#include <ros/node_handle.h>
#include <std_msgs/Bool.h>
#include <std_msgs/Float32.h>
#include <std_msgs/Int32.h>
#include <sensor_msgs/JointState.h>
#include <sensor_msgs/LaserScan.h>
#include <geometry_msgs/WrenchStamped.h>
#include <geometry_msgs/Point.h>
#include <geometry_msgs/Pose2D.h>
#include <geometry_msgs/Twist.h>
#include <Eigen/Dense>
#include <unsupported/Eigen/MatrixFunctions>


#include <math.h>
#include <vector>

//#include "vrep_franka_tutorial/moveitcontroller.h"

//-------------------Parameters------------------------------------------------
#define PI 3.14159265359
#define deg2rad(deg)  ((deg) * PI / 180.0)
#define rad2deg(rad)  ((rad) * 180.0 / PI)

#define MIN_OMEGA deg2rad(-15)// rad/s
#define MAX_OMEGA deg2rad(15) // rad/s

#define MIN_VELOCITY -0.05//s // m/s
#define MAX_VELOCITY 0.18 // m/s

#define MAX_VEL_ACCELATION 0.04 //m/s^2
#define MAX_OMEGA_ACCELATION deg2rad(15)  //m/s^2

#define MAX_DIST 0.6

#define VELOCITY_RESOLUTION 0.005
#define YAWRATE_RESOLUTION deg2rad(0.1)
#define SAMPlE_HZ    10// Hz
#define PREDICT_TIME 1.0

//--------------Gain---------------------------------------
#define HEADING_COST_GAIN_pole 0.008
#define HEADING_COST_GAIN_zero 0.83
#define DIST_COST_GAIN 1.50
#define SPEED_COST_GAIN 0.5
#define OBSTACLE_COST_GAIN 1.3

class DWA_Planner
{
public:
    DWA_Planner();

    class State
    {
    public:
        State(double _x, double _y, double _theata, double _v,double _w);

        double x;
        double y;
        double theata;
        double v;
        double w;
    private:
    };

    class Window
    {
    public:
        Window();
        Window(const double _v_min,const double _v_max,const double _w_min,const double _w_max);
        double v_min;
        double v_max;
        double w_min;
        double w_max;
    private:
    };

    //Call Back Method
    void scan_callback(const sensor_msgs::LaserScanConstPtr& msg);
    void goal_callback(const geometry_msgs::PointConstPtr& msg);
    void cur_pos_callback(const geometry_msgs::Pose2DConstPtr& msg);

    void process(void);
    void get(int mode){ this->mode = mode;}
    //Map Imforamtion
    std::vector<Eigen::Vector2f> scan_to_obs();

    //Navigation Methods
    DWA_Planner::Window calc_dynamic_window(const geometry_msgs::Twist& current_velocity);
    void motion(State& state, const double v, const double w);
    std::vector<State> Find_BestTrajectory(Window window,Eigen::Vector2f goal,std::vector<Eigen::Vector2f> obs_list);

    //Obj Function
    float safe_acos(float value);
    float calc_to_goal_cost(const std::vector<State>& traj, Eigen::Vector2f goal);
    float calc_speed_cost(const std::vector<State>& traj, const float target_velocity);
    float calc_obstacle_cost(const std::vector<State>& traj, const std::vector<Eigen::Vector2f>& Obsist);

private:
    ros::NodeHandle nh;

    ros::Publisher twist_pub;

    ros::Subscriber Scan_sub;
    ros::Subscriber goal_pose_sub;
    ros::Subscriber Current_Pose_sub;

    geometry_msgs::Twist current_velocity;
    geometry_msgs::Twist best_velocity;
    geometry_msgs::Pose2D Current_Pose;
    sensor_msgs::LaserScan scan;
    geometry_msgs::Point goal;

    Eigen::Vector3d Cur_pose;
    Eigen::Vector2f goal_area;

    State cur_state = State(0.0,0.0,0.0,0.0,0.0);

    bool scan_updated;
    bool position_updated;
    bool goal_updated;
    bool twist_updated;
    int  mode;

    double dt;
};

#endif

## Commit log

2020-11-28 처음 커밋입니다.
2020-11-28 설계 파일 업로드
2020-11-28 보고서
    보고서 업로드
2020-11-28 MCU 코드 업데이트
    main MCU인 jetbot에 들어가는 code 업로드
2020-11-28 설계파일과 보고서 업로드
    설계파일과 보고서 업로드
    [145pi_tire.0006.iam, 145pi_tire.iam, EX106_H.0015.ipt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]
2020-11-28 설계파일 업로드
    [145pi_tire.0006.iam, 145pi_tire.iam, EX106_H.0015.ipt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]
2020-11-28 시뮬레이션 scence
    시뮬레이션 업로드
2020-11-28 DWA
    DWA 알고리즘 업데이트
2020-11-28 코어텍스 코드업로드
    코어텍스 코드업로드
2020-11-28 보고서 수정
    보고서 수정 & 재업로드
2021-02-27 Mobile Robot's Motor test
    Dynamics를 고려한 v,w controller simulation을 통해 구동 가능성을 검증하고, 대략적인 성능을 파악
    모터제어 섹션의 영상에서 CoppeliaSim으로 부터 v,w를 입력받으면 그 때 controller와 plant를 거쳐 output인 각 모터의 각속도를 CoppeliaSim으로 전송
    위 코드는 그 때 controller와 plant를 구현한 코드
2021-04-01 Update README.md
    행간 수정

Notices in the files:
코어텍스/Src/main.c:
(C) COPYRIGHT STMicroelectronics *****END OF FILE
